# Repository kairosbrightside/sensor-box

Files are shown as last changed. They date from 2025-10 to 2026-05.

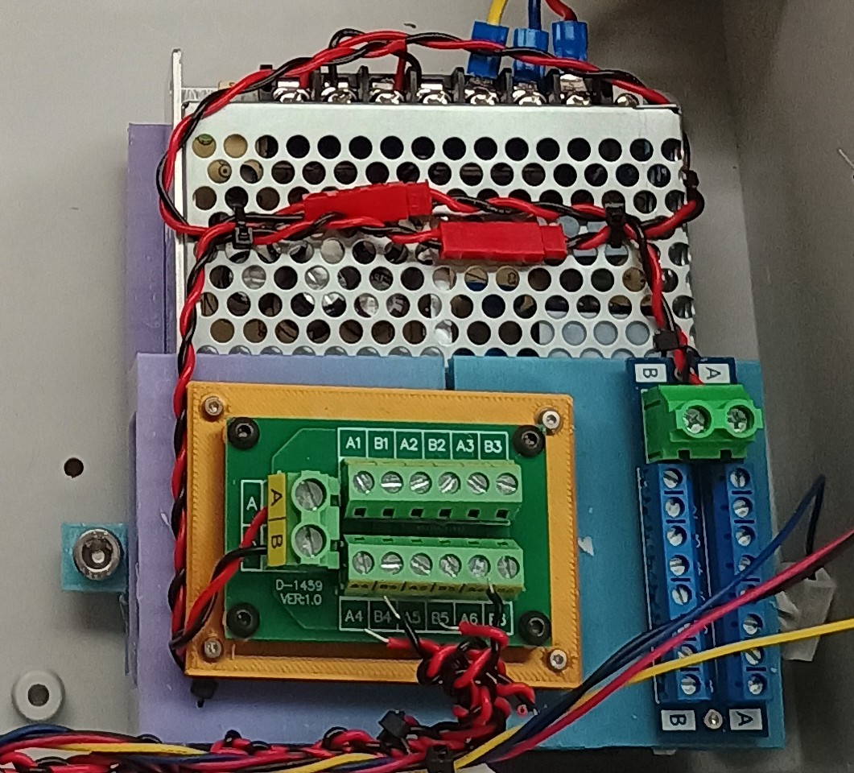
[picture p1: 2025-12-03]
images/powersupply.jpg

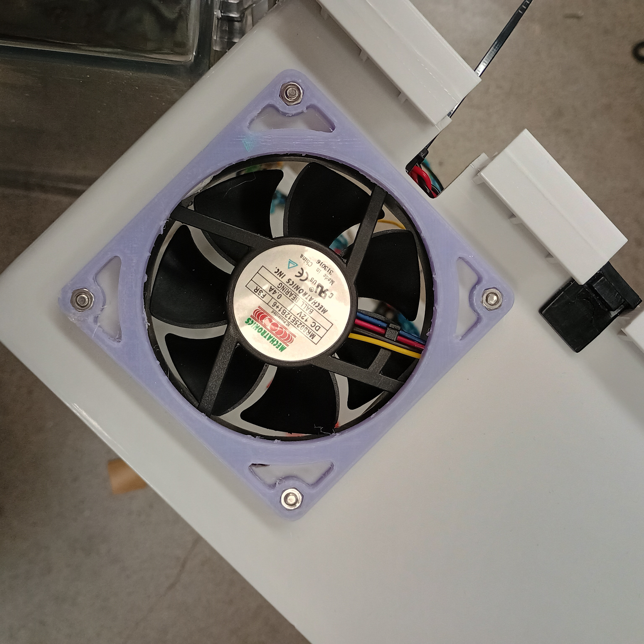
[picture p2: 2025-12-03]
images/fan.jpg

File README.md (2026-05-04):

# SensORV6
This Readme file contains information on the building and production of a Oregon SensOR box. The original information is found [here](https://github.com/ParticulateSensOR/SensORV6). Kairos here! I am building this as an expansion of a [project](https://github.com/kairosbrightside/sps30-pi) I did last summer (electrical documentation can be found there for the SPS30 sensor). I was supposed to do this like 2 months ago but I took too long on the autosampler `</3`. 

# Purpose
Sensor interface for real-time particulate monitoring using the SPS30 and Raspberry Pi, with CSV logging support.

# Equipment list 
| Component | Description / Model | Notes | Have? |
|---|---|---|---|
| PM2.5 Sensor | Plantower PMs5003ST | Measures particulate matter | ☑️ |
| PM2.5 Sensor | Sensirion SPS30 sensor | Measures particulate matter | ☑️ |
| Power Supply | RID-65A Meanwell (5V/12V) or RT-65D (5V/24V/12V) | Provides power etc | ☑️ |
| Computer | Raspberry Pi 5 | Main system controller | ☑️ |
| SD Card | SanDisk 64 GB SD Card | Storage for OS & data | ☑️ |
| Auto-Zero Valve | US Solid Motorized Ball Valve | Valve | ☑️ |
| 2x6 Terminal block | [Amazon Link](https://www.amazon.com/dp/B09D3BV22M?ref=ppx_yo2ov_dt_b_fed_asin_title) | Makes wiring easier | ☑️ |
| Heating Element | [Amazon Link](https://www.amazon.com/dp/B0CLS34QN2?ref=ppx_yo2ov_dt_b_fed_asin_title) | Heating | ☑️ |
| GPIO Terminal Block w/LED  | [Amazon Link](https://www.amazon.com/dp/B09QXR6RL7?ref=ppx_yo2ov_dt_b_fed_asin_title) | Easier GPIO wiring + indicators | ☑️ |
| Relay Board / RPi Hat | [Amazon Link](https://www.amazon.com/dp/B07CZL2SKN?ref=ppx_yo2ov_dt_b_fed_asin_title) | Turns stuff on and off | ☑️ |
| Diaphragm Pump | <Will Insert Later> | Supplies clean reference air | ☑️ |
| Rheostat | <Will Insert Later> | Adjusts current / heating power | ☑️ |
| Sensor Box | <Will Insert Later> | Enclosure for system | ☑️ |
| 80 mm computer fan | generic? | Fan | ☑️ |

Plus wire, connectors, filament, screws, tools, etc?

# Picture
SensOR box

Plantower sensor pinout


### wiring table 
| Physical Pin | BCM | Function  | Connection |
|---|-----|---|---|
| 6 | — | GND | Ground for ALL devices |
| 7 | 4 | GPIO4 | Button |
| 8 | 14  | TXD0 | SPS30 → RX  (UART0) |
| 10 | 15  | RXD0 | SPS30 ← TX (UART0) |
| 11 | 17  | GPIO17 | Fan tachometer |
| 27 | 0 | TXD1 | Plantower #1 → RX (UART1 TX → Pi RX)  |
| 28 | 1 | RXD1 | Plantower #1 ← TX (UART1 RX ← Pi TX)  |
| 32 | 12  | TXD4 | Plantower #2 → RX (UART4 TX → Pi RX)  |
| 33 | 13  | RXD4 | Plantower #2 ← TX (UART4 RX ← Pi TX)  |
| 37 | 26  | GPIO26 | Plantower power (Relay1) |
| 38 | 20  | GPIO20 | Heater (Relay2) |
| 40 | 21  | GPIO21 | Zero pump  (Relay3, NC) |
| 40 | 21  | GPIO21 | Valve  (Relay3, NO) |



> Note: we are skipping UART2 since we are using gpio 4 (physical pin 7) for something else

### changing UART settings
``` /boot/firmware/config.txt```
```bash
enable_uart=1
dtoverlay=uart1
dtoverlay=uart4
```
##### Checking changed UART settings:
Use 
```bash
ls /dev/ttyAMA*
```
to make sure all the desired ports (0,1,4) are available. When sensors are connected, check output with 
```bash
sudo cat /dev/ttyAMA0
sudo cat /dev/ttyAMA1
sudo cat /dev/ttyAMA4
```
### 5V devices:
Particle sensors (3x), level shifters

### Connect to Pi 3.3V output
The `SET` and `RESET` pins of the Plantower sensors.

### 12V devices:
Fan, Pumps, motorized ball valce, heater strip+ (rheostat)

## System functions:
The system takes in air through the top, when the valve is open and the relay is connected to the NO terminal. When the valve is closed, the zero air pump is calibrating the system by running zero air through it. The fan at the bottom blows out the air. The heater in the tube keeps temperature constant to ensure a constant volume enters the sample chamber.

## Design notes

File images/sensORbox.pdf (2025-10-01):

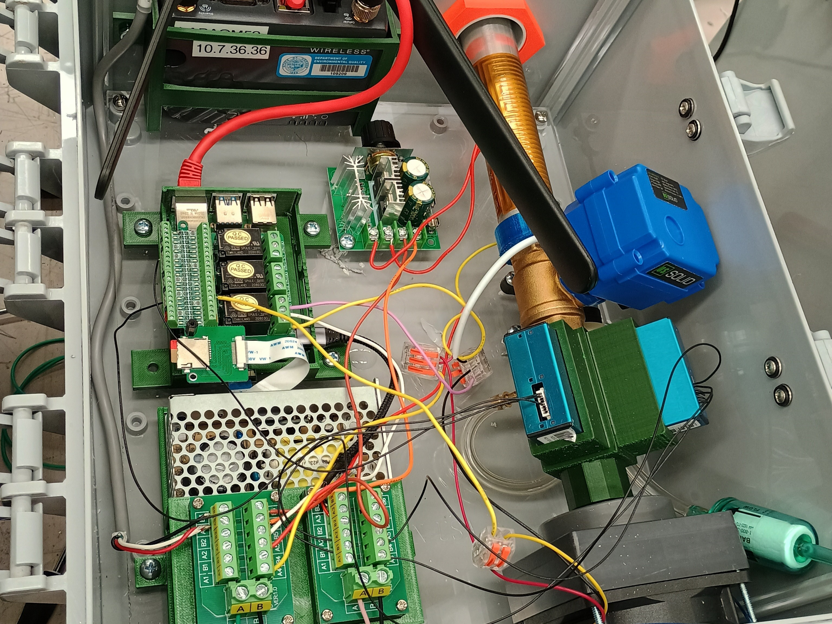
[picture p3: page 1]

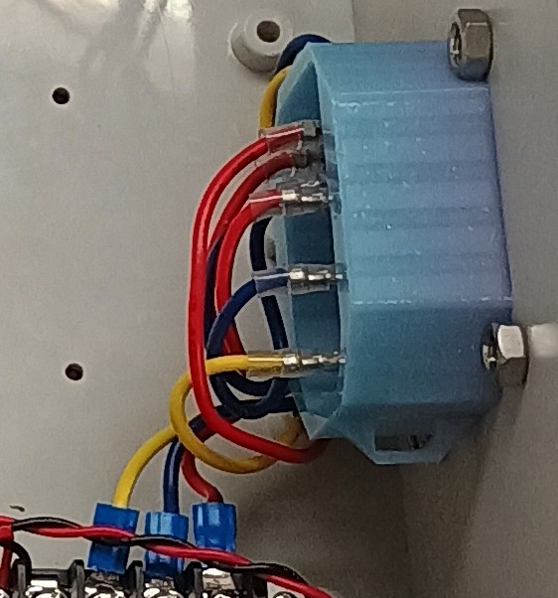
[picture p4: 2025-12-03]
images/systempowerback.jpg

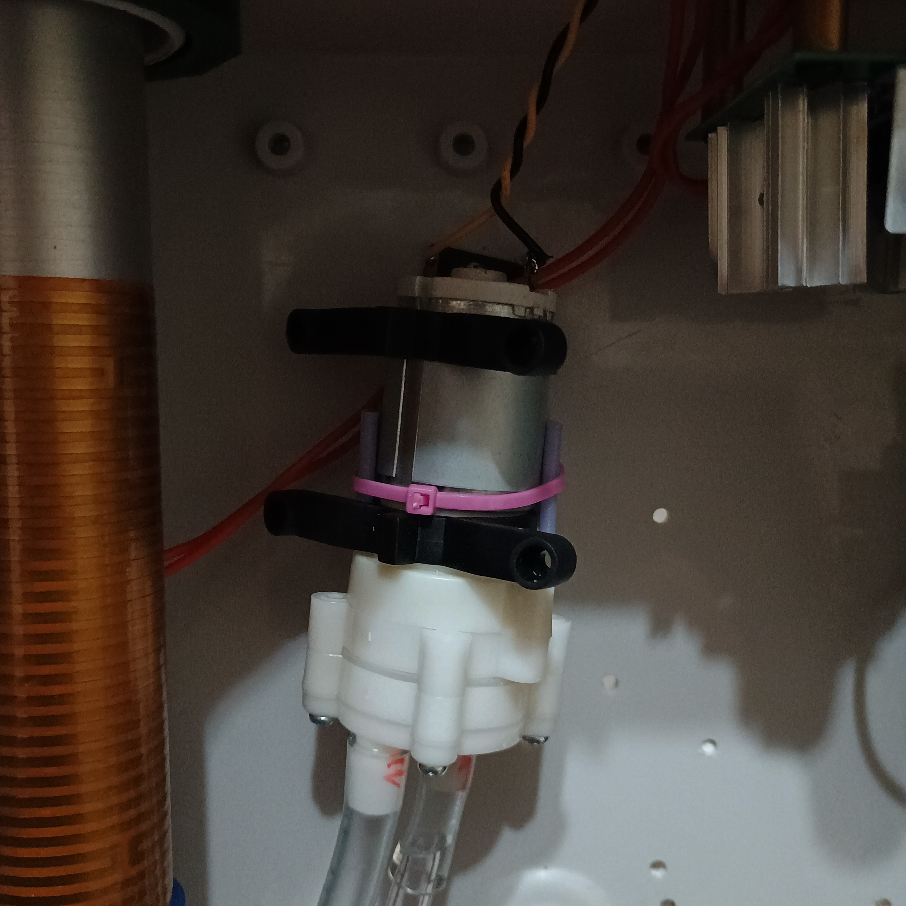
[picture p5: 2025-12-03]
images/pump.jpg

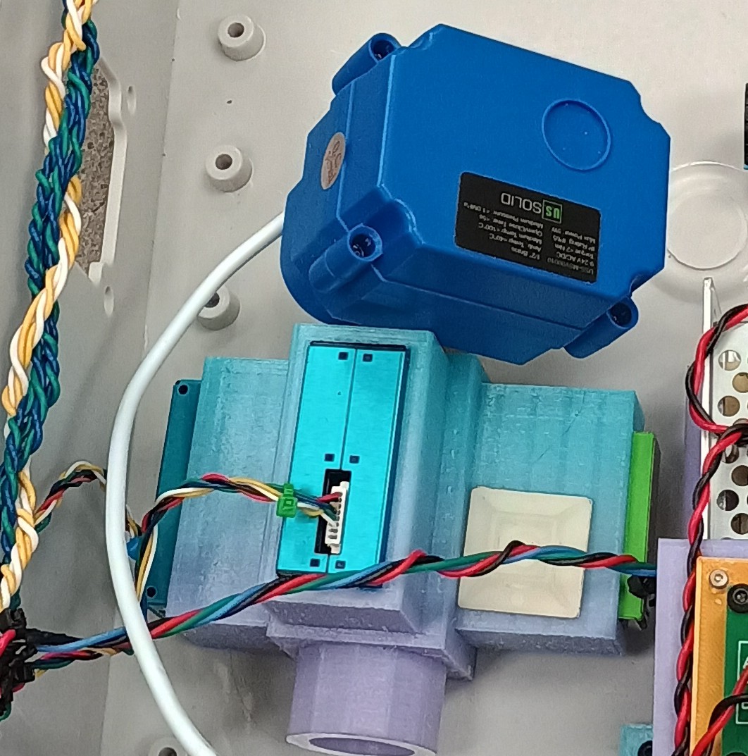
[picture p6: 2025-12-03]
images/samplechamber.jpg

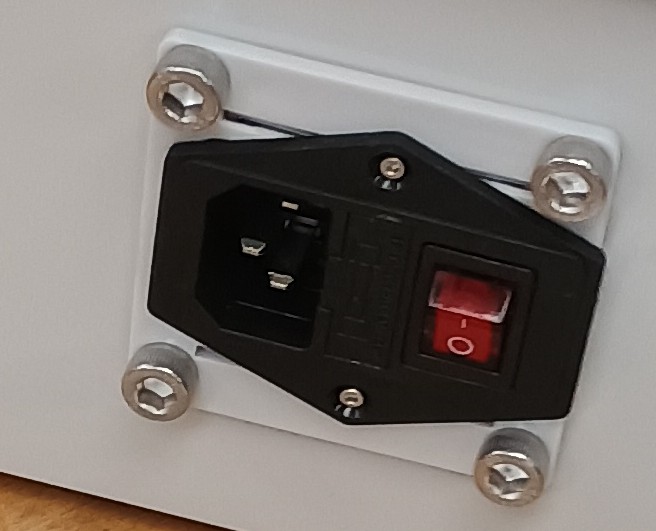
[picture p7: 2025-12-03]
images/sytstempower.jpg

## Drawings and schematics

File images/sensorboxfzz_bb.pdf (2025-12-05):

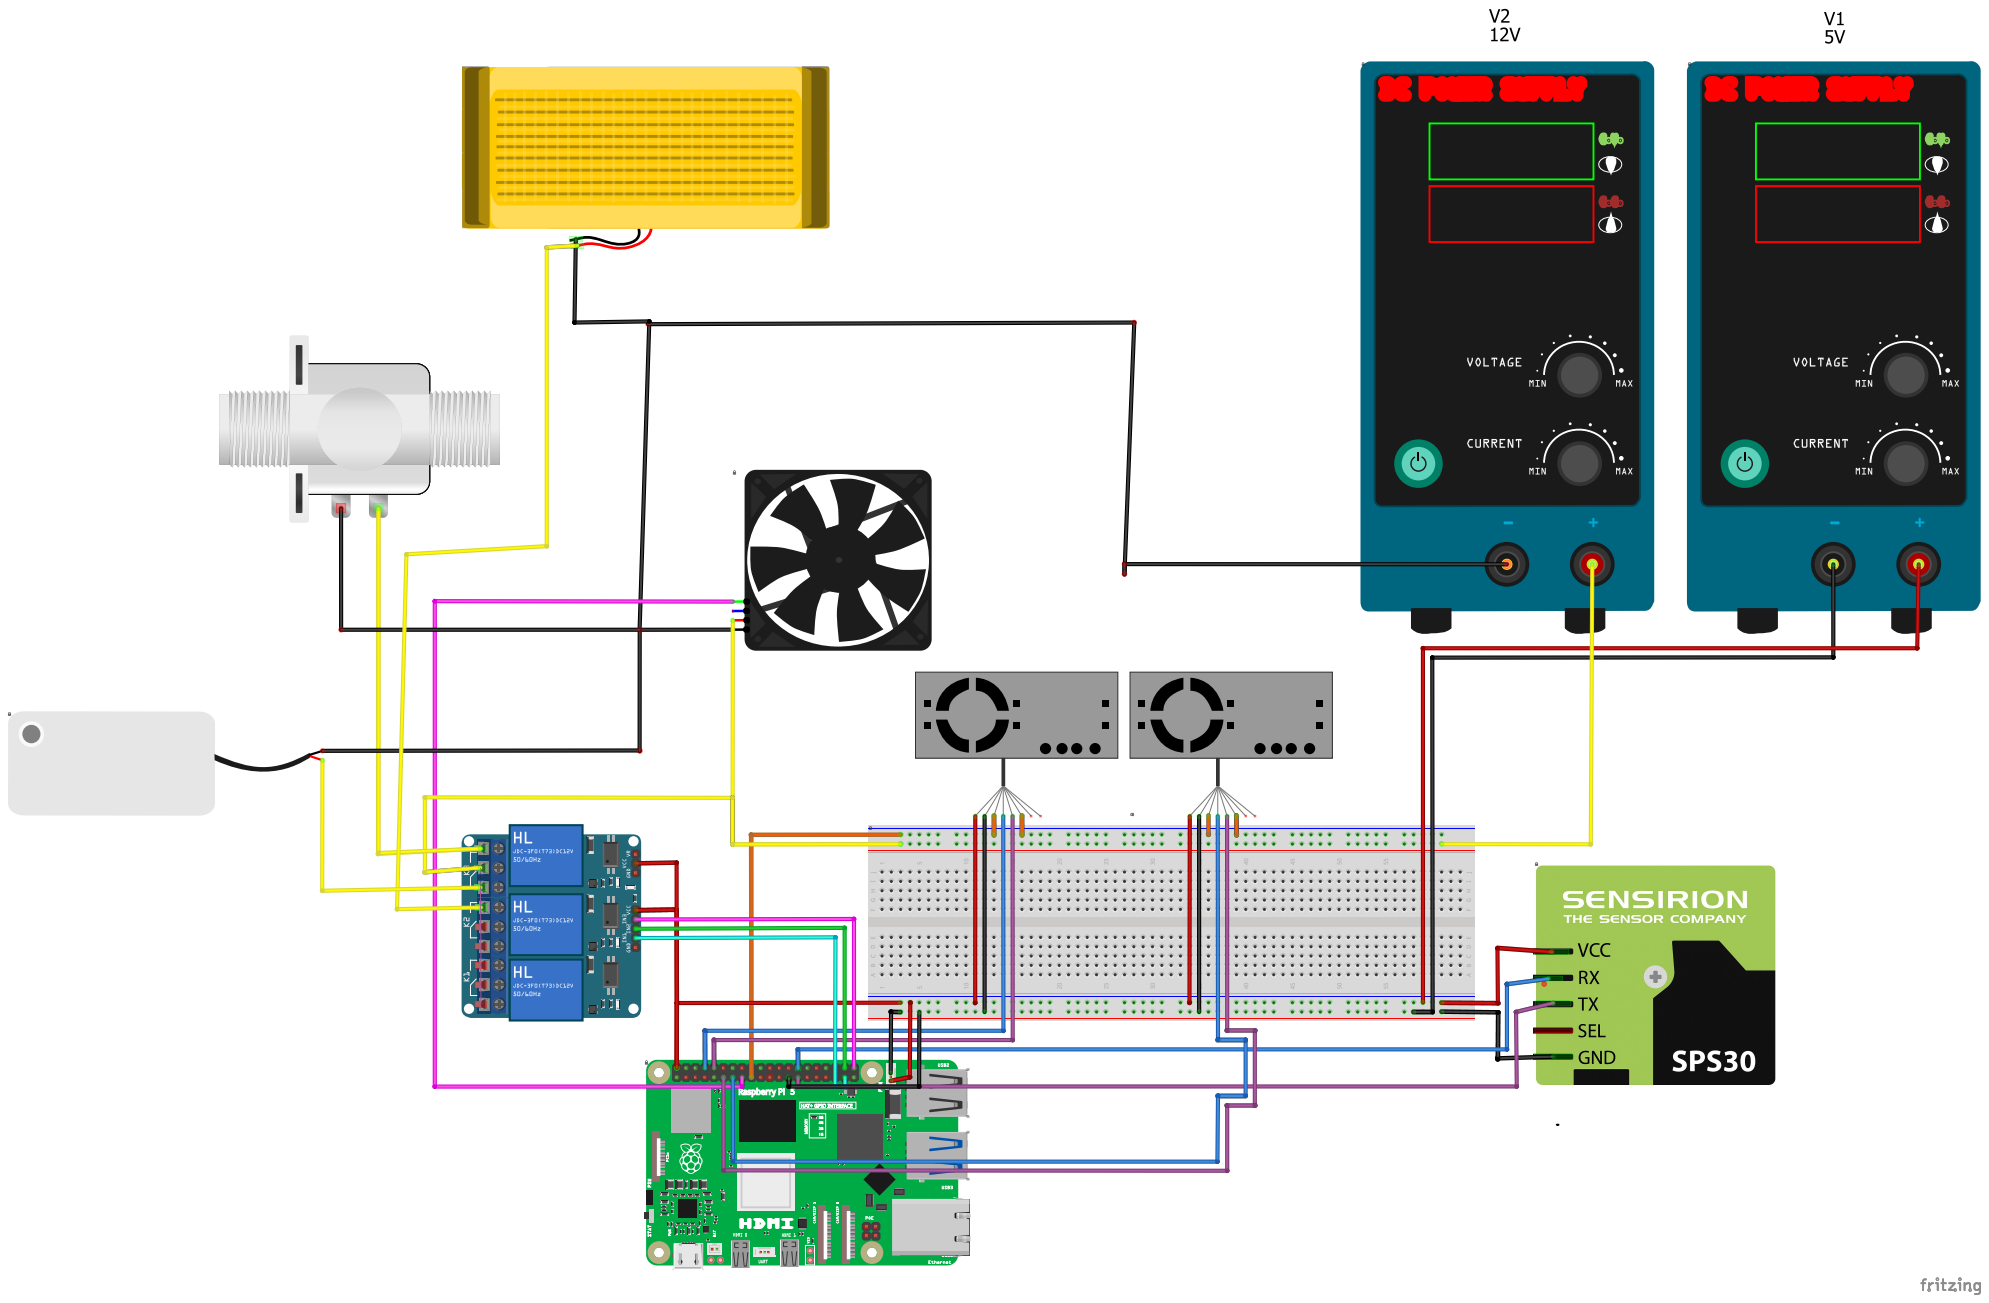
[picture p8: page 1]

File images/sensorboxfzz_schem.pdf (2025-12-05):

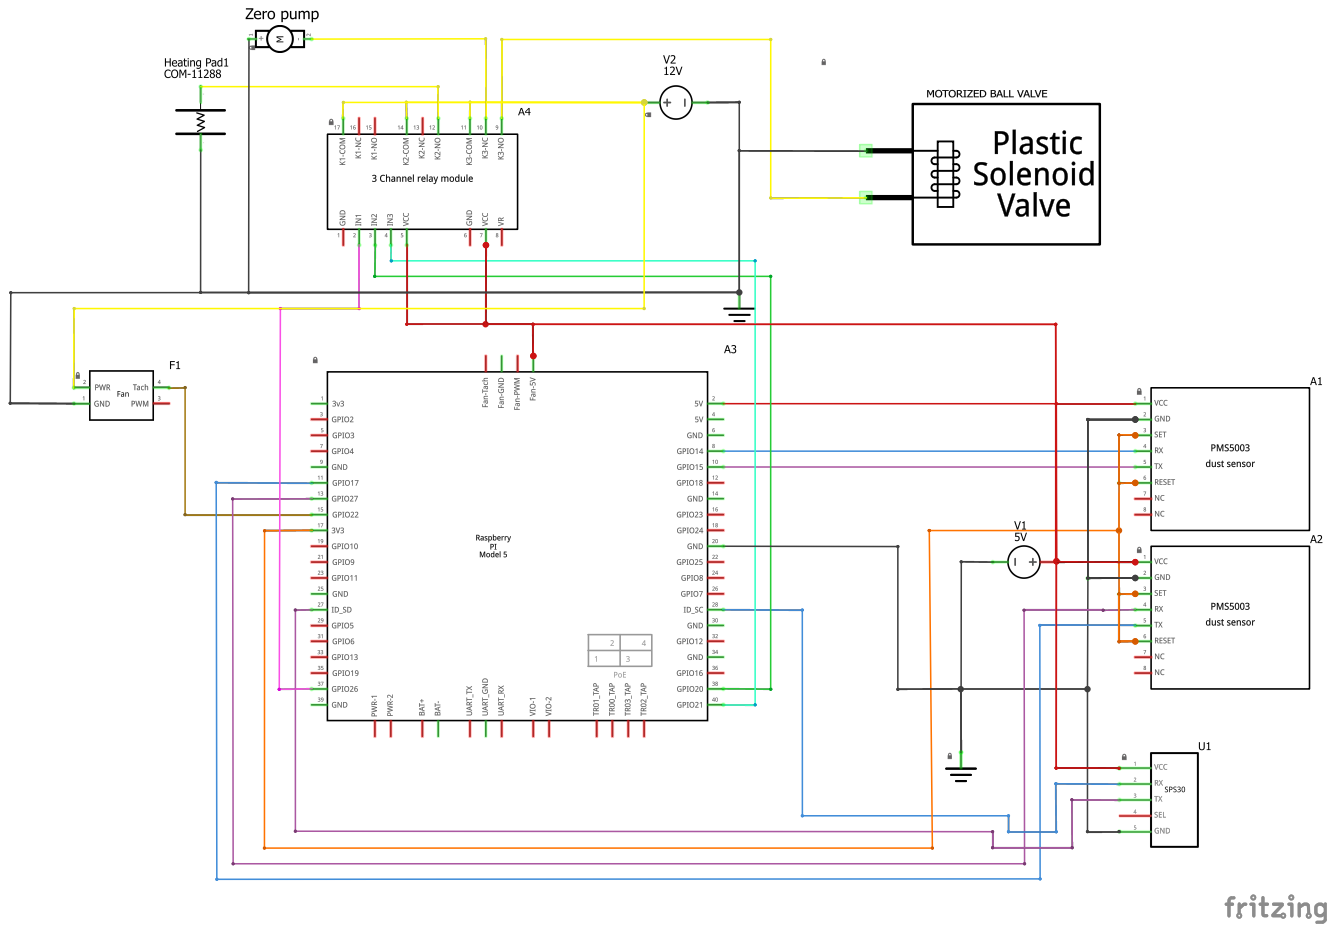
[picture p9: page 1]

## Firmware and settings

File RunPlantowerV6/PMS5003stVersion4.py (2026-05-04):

#This script reads data from PMS5003st sensors 
# The script is broken into 10 sections:
##(0) import libraries 
##(1) inputs for shell
##(2) make a log file
##(3) define functions
##(4) write header
##(5) On RPi storage - daily records & init minute data for shipping
##(6) check zero
##(7) establish RPi-plantower serial connection 
##(8-10) read plantower data, aggregate, and write to disk

# updated 9DEC2020 by AWF
#########################################  
#(0) libraries
##########################################
import os, sys
import shutil

import datetime, time
import serial
import RPi.GPIO as GPIO
import numpy as np
import pandas as pd

import logging

import struct

#########################################  
#(1) input from shell & adjust here
#########################################
site = sys.argv[1]
site = str(site)

##
sn = sys.argv[2]
sn = str(sn)

##
Port2Focus = sys.argv[3]
Port2Focus = str(Port2Focus)

# uncomment for testing
#site="BOX"
#sn="2"
#Port2Focus="ttyAMA1"

#adjust here
code_version = 4
sensorType = "PMS5003st"
DataOutDirectory = "/media/particulatepi/data/PMoutputData/" #output directory

SampleRate = 2 #sec - pause n seconds between measurements

######################################### 
#(2) create log
######################################### 
fleLog = (DataOutDirectory + site + "_" + sensorType + "_sn" + sn + "_" + "Log.txt")

logger = logging.getLogger(__name__)
logger.setLevel(logging.DEBUG)

formatter = logging.Formatter('%(asctime)s:%(filename)s:%(funcName)s:%(levelname)s:%(levelno)s:%(message)s')

file_handler = logging.FileHandler(fleLog)
file_handler.setFormatter(formatter)

logger.addHandler(file_handler)

######################################### 
#(3) functions 
#########################################
# connect to the sensor
def plantower_serial_connection(_serPort):
    '''Establishes serial connection between RPi and plantower:
    inputs: _serPort = RPi port attached to plantower
    
    returns: ser = serial object for the plantower connection
    ErrorFlag = error message associated with a failed serial connection w/"none" == no errors/connection is OK''' 
    
    ErrorFlag = 'init'
    IsPortOpen = False
    nTrys = 0
    
    while ((IsPortOpen == False) & (nTrys <= 3)):
        
        #make a connection
        try:
            ser = serial.Serial() #serial object
            ser.port = '/dev/' + _serPort  
            ser.baudrate = 9600
            ser.stopbits = serial.STOPBITS_ONE
            ser.parity = serial.PARITY_NONE
            ser.bytesize = serial.EIGHTBITS
            ser.timeout = 5
            
            ser.open()
            IsPortOpen = ser.is_open
            ErrorFlag = 'none'
            
        except:
            
            nTrys += 1
            logger.info('Could not make a serial object.')
            time.sleep(1)#pause
    
    return(ser, ErrorFlag)


# read in the serial string from the plantower and do basic QA/QC
def read_pm_line(_port):
    '''Reads serial data from plantower
    inputs: _port = serial object from plantower_serial_connection
    
    return:
    rv is the data (serial string) from the plantower
    error_read_pm_line = error message associated with a failed serial read w/ "none" == all OK'''
    
    #initialize
    nSearchForStartReads = 0
    rv = b''
    error_read_pm_line = 'error_read_pm_line'
    
    #do the read
    while ((error_read_pm_line != 'none') & (nSearchForStartReads < 100)):
        try:
            nSearchForStartReads += 1
            
            #PMS5003st gives a 40 character string
            ch1 = _port.read()
            if ch1 == b'\x42':
                ch2 = _port.read()
                if ch2 == b'\x4d':
                    rv += ch1 + ch2
                    rv += _port.read(38)
                    
                    error_read_pm_line = 'none'

        except:
            rv = b''
            
    return(rv, error_read_pm_line)
            
# error check for incoming serial data          
def read_pm_error_check(rv, error_read_pm_line):
    '''Error checking on read_pm_line'''
    
    err_check = error_read_pm_line
    
    ##check if a base error was thrown
    if (error_read_pm_line != 'none'):
        logger.info('error_read_pm_line')
        err_check = 'err_flag'
    ##did not get a read
    if (rv == b''):
        logger.info('EmptyReadLine')
        err_check = 'err_flag'
    ##length 
    if (len(rv) != 40):
        logger.info('ReadLineLengthError')
        err_check = 'err_flag'
    ##check sum 
    if (len(rv) == 40):
        DataSum = sum(rv[0:37])
        cksum = (rv[38] * 256 + rv[39])
        if (DataSum != cksum):
            logger.info('CheckSumFailError')
            err_check = 'err_flag'
    
    return(rv, err_check)
    
# file management - check read-write      
def SetupDataFile(fleOut, writetype):
    '''check file permissions'''
    
    if os.path.exists(fleOut) == True:
        logger.info('Restarting Run: Appending data to' + fleOut) 
    else:
        try:
            file2write = open(fleOut, writetype)
            file2write.close()
        except:
            logger.info('Setup file Error')
            
        OKfilePermission = (os.access(fleOut, os.R_OK)) & (os.access(fleOut, os.W_OK)) #read-write privaleges?
        if (OKfilePermission == False):
            logger.info('File Permission Error: ' + fleOut + ' Exiting!') 
            sys.exit(1) #exit


def init_dataout(fleoutAVG, PMheader):
    '''init data to file'''
    
    InitData = pd.DataFrame(999, index=range(0,1), columns = PMheader) # initialize

    try:
        with open(fleoutAVG, 'w') as myfile:
            InitData.to_csv(myfile, header=False, index=False)
    except:
        logger.info("data.csv did not initalize.")
  
  
#######d##################################
#(4) write the header to disk
#########################################
fleHeader = (DataOutDirectory + site + "_" + sensorType + "_sn" + sn + "_" + "DataHeader.txt")
    
PMheader = ["year", "month", "day", "hour", "minute", "second",
            "apm1_0", "apm2_5", "apm10",
            "pm1_0", "pm2_5", "pm10",
            "gt03um", "gt05um", "gt1_0um", "gt2_5um", "gt5_0um", "gt10um",
            "form",
            "T_K",
            "rh", "zero",
            "code_version", "sn"]

HeaderLine = ",".join(PMheader) + "\n"

with open(fleHeader, "a") as myfile:
    myfile.write(HeaderLine)
               
######################################################################
## (5) On RPi storage - daily records & init minute data for shipping
######################################################################
DateStr4Out = str(datetime.datetime.now().day) + '_' + str(datetime.datetime.now().month) + '_' + str(datetime.datetime.now().year)
        
fleoutFSTDaily = (DataOutDirectory + site + "_" + sensorType + "_sn" + sn + "_" + "1sec" + DateStr4Out + ".txt")
SetupDataFile(fleoutFSTDaily, "a")       
        
fleoutAVGDaily = (DataOutDirectory + site + "_" + sensorType + "_sn" + sn + "_" + "1Min" + DateStr4Out + ".txt")
SetupDataFile(fleoutAVGDaily, "a")

# setup the file for data that will be loaded to the modbus server - this will get updated every minute
fleoutAVG = (DataOutDirectory + site + '_' + sensorType + "_sn" + sn + "_" + "1Min.txt")
SetupDataFile(fleoutAVG, "a")
init_dataout(fleoutAVG, PMheader)

########################################
## (6) check zero 
#########################################
 
try:
    pinhigh = GPIO.input(21)
except:
    logger.info("PMS5003st code set the zero pin to low.")
    GPIO.setmode(GPIO.BCM) # updated BCM to BOARD 12SEP2023
    GPIO.setup(21, GPIO.OUT)
    GPIO.output(21, GPIO.LOW)
    pinhigh = 0
    
#########################################
# (7) Connect to sensor
#########################################
ser, ConnectionError = plantower_serial_connection(Port2Focus)

if (ConnectionError == 'none'):
    logger.info("Connected to " + sensorType) 
else:
    ### Give up and report the failure
    logger.info("Exiting " + sensorType + " connection: " + str(ConnectionError)) 
    sys.exit(1) #exit 

########################################
# (8) Read serial data from plantower
########################################
#Initialize
iter = 0
MeasureTime = datetime.datetime.utcnow() - datetime.timedelta(hours=8)
Day_previous = MeasureTime.day
minute_past  = MeasureTime.minute

#Initiate a dataframe for the incoming data
DataIn = pd.DataFrame(999, index=range(0,1),columns=PMheader)

IndRow = 0
 
while True:
    try:
        
        #sets sampling rate
        time.sleep(SampleRate) 
            
        #time - should not observe daylight savings
        MeasureTime = datetime.datetime.utcnow() - datetime.timedelta(hours=8)
        
        #Clear input buffer to avoid lagging, was done after each minute before
        ser.flushInput()
        
        rcv, error_read_pm_line = read_pm_line(ser) #read in serial data
        
        # for troubleshooting
        # print(rcv)
        
        rcv, read_error = read_pm_error_check(rcv, error_read_pm_line)

        # for troubleshooting
        # print(rcv)
        # print(read_error)
        
        if (read_error == 'none'):
            #Parse rcv serial string to DataIn: see PMS5003st manual for var. assignments
            DataIn.loc[IndRow,"year"]  = int(MeasureTime.year)        #time block
            DataIn.loc[IndRow,"month"]  = int(MeasureTime.month)
            DataIn.loc[IndRow,"day"]  = int(MeasureTime.day)
            DataIn.loc[IndRow,"hour"]  = int(MeasureTime.hour)
            DataIn.loc[IndRow,"minute"]  = int(MeasureTime.minute)
            DataIn.loc[IndRow,"second"]  = int(MeasureTime.second)
                
            DataIn.loc[IndRow,"apm1_0"]  = int(rcv[4] * 256 + rcv[5])    #apm block
            DataIn.loc[IndRow,"apm2_5"]  = int(rcv[6] * 256 + rcv[7])                
            DataIn.loc[IndRow,"apm10"]  = int(rcv[8] * 256 + rcv[9])                
                
            DataIn.loc[IndRow,"pm1_0"]  = int(rcv[10] * 256 + rcv[11])  #pm block
            DataIn.loc[IndRow,"pm2_5"] = int(rcv[12] * 256 + rcv[13])             
            DataIn.loc[IndRow,"pm10"] = int(rcv[14] * 256 + rcv[15])              
                   
            DataIn.loc[IndRow,"gt03um"] = int(rcv[16] * 256 + rcv[17]) #gt block
            DataIn.loc[IndRow,"gt05um"] = int(rcv[18] * 256 + rcv[19])
            DataIn.loc[IndRow,"gt1_0um"] = int(rcv[20] * 256 + rcv[21])
            DataIn.loc[IndRow,"gt2_5um"] = int(rcv[22] * 256 + rcv[23])
            DataIn.loc[IndRow,"gt5_0um"] = int(rcv[24] * 256 + rcv[25])
            DataIn.loc[IndRow,"gt10um",] = int(rcv[26] * 256 + rcv[27])
                   
            DataIn.loc[IndRow,"form"] = int(((rcv[28] * 256 + rcv[29])/1000))  #formaldehyde
                
            # there is a multiplier = 10 from the plantower
            DataIn.loc[IndRow,"T_K"] = int(round((((struct.unpack('>20h',rcv)[15])/10) + 273.15) * 10, 0))  #temp in Kelvin
            
            DataIn.loc[IndRow,"rh"] = int(rcv[32] * 256 + rcv[33]) #rh * 10
            
            DataIn.loc[IndRow,"zero"] = int(GPIO.input(21)) #zero
            
            DataIn.loc[IndRow,"code_version"] = int(code_version) # version of code
            DataIn.loc[IndRow,"sn"] = int(sn) # sn
            
            #add 1 to row index for next loop
            IndRow += 1 
            
            # reset iter
            iter = 0
            
        elif ((read_error != 'none') & (iter > 50) & (iter <= 99)):
            ser, ConnectionError = plantower_serial_connection(Port2Focus)
            logger.info("Error: Restarting Connection")
            
            iter += 1
            
        elif ((read_error != 'none') & (iter > 99)):
            logger.info("## N try > 99, writing 999 to data")
            init_dataout(fleoutAVG, PMheader) # write out 999 to minute data on exit

        else:
            iter+=1

            
        ############################################################
        #(9) write data at 1 min. interval
        ############################################################
        #save data to disk
        minute_current = MeasureTime.minute
        
        if (minute_current != minute_past):
            
            minute2send = pd.DataFrame(999, index=range(0,1), columns=PMheader)
  
            try:
                #do the ENVIDAS aggregation
                
                minute2send.loc[0,"apm1_0"] = DataIn["apm1_0"].mean().round(0) #avg apm mass
                minute2send.loc[0,"apm2_5"] = DataIn["apm2_5"].mean().round(0)
                minute2send.loc[0,"apm10"] = DataIn["apm10"].mean().round(0)
                
                minute2send.loc[0,"pm1_0"] = DataIn["pm1_0"].mean().round(0) #avg pm mass
                minute2send.loc[0,"pm2_5"] = DataIn["pm2_5"].mean().round(0)
                minute2send.loc[0,"pm10"] = DataIn["pm10"].mean().round(0)
                
                minute2send.loc[0,"gt03um"] = DataIn["gt03um"].mean().round(0)  #avg particle counts
                minute2send.loc[0,"gt05um"] = DataIn["gt05um"].mean().round(0)
                minute2send.loc[0,"gt1_0um"] = DataIn["gt1_0um"].mean().round(0)
                minute2send.loc[0,"gt2_5um"] = DataIn["gt2_5um"].mean().round(0)
                minute2send.loc[0,"gt5_0um"] = DataIn["gt5_0um"].mean().round(0)
                minute2send.loc[0,"gt10um"] = DataIn["gt10um"].mean().round(0)
                
                minute2send.loc[0,"form"] = DataIn["form"].mean().round(0) #avg formaldehyde
                minute2send.loc[0,"T_K"] = DataIn["T_K"].mean().round(0) #avg temp
                minute2send.loc[0,"rh"] = DataIn["rh"].mean().round(0) #avg rh
                
                minute2send.loc[0,"zero"] = DataIn["zero"].mean().round(0) #doing zero
                
                minute2send.loc[0,"code_version"] = DataIn["code_version"].median().round(0) #code version
                minute2send.loc[0,"sn"] = DataIn["sn"].median().round(0) #sn
                
                minute2send.loc[0,"year"] = DataIn["year"].median().round(0) # time
                minute2send.loc[0,"month"] = DataIn["month"].median().round(0)
                minute2send.loc[0,"day"] = DataIn["day"].median().round(0)
                minute2send.loc[0,"hour"] = DataIn["hour"].median().round(0)
                minute2send.loc[0,"minute"] = DataIn["minute"].median().round(0)
                minute2send.loc[0,"second"] = DataIn["second"].median().round(0)
                
            except:
                logger.info("Minute could not be averaged. May be empty.")
            
            #Reset the minute for record keeping
            minute_past = minute_current
              
            try:
                with open(fleoutAVG, 'w') as myfile1:
                    minute2send.to_csv(myfile1, header=False, index=False, float_format='%.0f')
                    
                with open(fleoutAVGDaily, "a") as myfile2:
                    minute2send.to_csv(myfile2, header=False, index=False, float_format='%.0f')
                    
            except:
                logger.info("Error: Did not write data to server")
            
            ####### RPi Backup logs #########################   
            #save if there is free space
            total, used, free = shutil.disk_usage(DataOutDirectory)
            
            fracFree = free/total
            
            if (fracFree >= 0.3):
                #fast data
                try:
                    with open(fleoutFSTDaily, "a") as myfile:
                        DataIn.to_csv(myfile, header=False, index=False)
                except:
                    logger.info("Fast file write error")
                    
            else:
                logger.info("Low disk space. Stopped logging data to local site")
                
            #Reset DataIn for incoming data
            IndRow = 0
            DataIn = pd.DataFrame(np.nan, index=range(0,1),columns=PMheader)
            
        ############################################################
        #(10) new file every day
        ############################################################
        #make a new file for data output
        Day_current = MeasureTime.day
        
        if (Day_current != Day_previous):
            
            DateStr4Out = str(Day_current) + '_' + str(MeasureTime.month) + '_' + str(MeasureTime.year)

            fleoutFSTDaily = (DataOutDirectory + site + "_" + sensorType + "_sn" + sn + "_" + "1sec" + DateStr4Out + ".txt")
            SetupDataFile(fleoutFSTDaily, "a")       
            
            fleoutAVGDaily = (DataOutDirectory + site + "_" + sensorType + "_sn" + sn + "_" + "1Min" + DateStr4Out + ".txt")
            SetupDataFile(fleoutAVGDaily, "a",)
            
            Day_previous = Day_current
            
    except:
        
        logger.info("!!Crashed!!")
        init_dataout(fleoutAVG, PMheader) # write out 999 to minute data on exit
        ser.close() # close the serial connection
        sys.exit(1) # exit the program

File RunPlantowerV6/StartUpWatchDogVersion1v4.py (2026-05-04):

#Watchdog to check if the sensor package started correctly
#alerts OP if box is working or not

##WORKING == 20 quick continuous pump buzzes
##NOT WORKING == 5 syncopated pump buzzes

#Check @ startup includes:
#(1) Check if the internet is working
#(2) Check if all key python scripts started
#(3) Check if the data that is being written to file is current with RPi time

#This script was modified to check if the button script is running

#Change as needed:
RunPMShell = '/home/particulatepi/RunPlantower/RunPMShell.sh'
DataDir = '/media/particulatepi/data/PMoutputData/' #Where is the data stored?
ip2ping = '192.168.13.101'      #Modem gateway connected to RPi?
#ip2ping = '192.168.1.1'      #Modem gateway connected to RPi?

#libraries
import sys
import subprocess, os
import datetime, time
import RPi.GPIO as GPIO 

import CheckOperationVersion1v3 as CheckOP

#main
def doWatchDog(print2screen):
    if (print2screen == 1):
        print('Print diagnostics to screen:')
                
    #(0) Init
    #setup GPIO pins
    GPIO.setwarnings(False)
    GPIO.setmode(GPIO.BCM)
    GPIO.setup(21, GPIO.OUT)

    #tell the OP that the box started the watchdog
    CheckOP.AlertOPpause(1)
    
    #init parameters for checks; 0 = off; 1 = on
    InternetUp = 0
    ScriptsUp = 0
    FilesUp = 0

    ### Main script ###
    #(1) Check if the box is connected to the internet
    if (print2screen == 1):
        print('Is the internet up:')
        
    FailedConnection = 0
    nTry = 60 # 0.5 min. trys

    while(InternetUp == 0):
        
        time.sleep(1) 
        
        PacketLoss = CheckOP.CheckInternet(ip2ping)
            
        if(PacketLoss == 0):
            InternetUp = 1
            if (print2screen == 1):
                print('Internet OK')
        else:
            InternetUp = 0
            FailedConnection += 1
        
        #try restarting networking if the internet is down
        if(FailedConnection == round(nTry/2)):
            try:
                if (print2screen == 1):
                    print('Could not ping modem:')
                    print('restart network connection')
                subprocess.run(['systemctl', 'restart', 'networking'])
            except:
                pass
        
        #alert OP if we did not establish a connection
        if(FailedConnection >= nTry):
            if (print2screen == 1):
                print('no connection')
            break
            
    #(2)Check if all the python programs started up?
    if (print2screen == 1):
        print('Check if scripts are running:')
                    
    FailedScript = 0
    nTry = 10 # 120 trys - 2 minutes

    while(ScriptsUp == 0):
        
        PythonUpTEMP = subprocess.Popen(['ps', '-ef'], stdout=subprocess.PIPE) #will this close itself?
        PythonUp = subprocess.check_output(['grep', 'python3.9'], stdin=PythonUpTEMP.stdout)
        PythonUp = PythonUp.decode("utf-8")

        serverStart = PythonUp.find("UpdateServer")
        plantowerStart = PythonUp.find("PMS5003stVersion")
        serialConnectionStart = PythonUp.find("ttyAMA0")
        usbConnectionStart = PythonUp.find("ttyAMA1")
        zeroStart = PythonUp.find("DoZero")
        # buttonStart = PythonUp.find("Button")
        
        #if any of the scripts are not running, kill all python processes and then restart them
        if((serverStart == -1)|(plantowerStart == -1)|(serialConnectionStart == -1)|(usbConnectionStart == -1)|(zeroStart == -1)):
                
            # subprocess.run(['sudo pkill -9', 'python'])
            
            CheckOP.RestartRunPMShell(RunPMShell)   
            
            FailedScript+=1
            
            if (print2screen == 1):
                print('script error: restarting scripts')
            
            time.sleep(15)
            
        else:
            ScriptsUp = 1
            if (print2screen == 1):
                print('scripts OK')
            
        #shutdown if we could not establish a connection
        if FailedScript >= nTry:
            if (print2screen == 1):
                print('scripts not running')
            break
        
    #(3) Check if current data is written to file
    if (print2screen == 1):
        print('SensOR clock says the time is:')
        print(datetime.datetime.now())
        print('Check if the datafile contains the current time:')
        
    FleInDir = os.listdir(DataDir)
    WhatIsLateInMin = 2 # it takes around 3 minutes to assure an update

    #How many 1 Min files are there?
    HowManyFilesShouldBeUpdated = 0

    #Get the number of files that should be updated
    for items in FleInDir:
        WhatFle = items.find('1Min.txt')
        if(WhatFle != -1):
            HowManyFilesShouldBeUpdated+=1

    #How many of these files are updated?
    FailedUpdate = 0
    nTrys = 100

    while (FilesUp == 0):
        
        nUpdatedFiles = CheckOP.IsLateMeasurement(DataDir, FleInDir, WhatIsLateInMin)
        
        if(nUpdatedFiles == HowManyFilesShouldBeUpdated):
            if (print2screen == 1):
                print('Data OK')
            FilesUp = 1
        else:
            FilesUp = 0
            
        #restart shell if proc are not updating
        if ((FilesUp == 0) & (FailedUpdate == (nTrys/2))):
            
            CheckOP.RestartRunPMShell(RunPMShell)
            
            if (print2screen == 1):
                print('Data not current: try restarting scripts')
                
            time.sleep((WhatIsLateInMin*60)/nTrys) #equally spaced effort
            
        if ((FilesUp == 0) & (FailedUpdate > nTrys)):
            if (print2screen == 1):
                print('Data not current: giving up - check plantower connections')
            break
        
        FailedUpdate+=1 
        time.sleep((WhatIsLateInMin*60)/nTrys)
        
        
    #(4)Alert the tech that the box started up OK or not
    ## if not --> shutdown
    if (InternetUp == 1) & (ScriptsUp == 1) & (FilesUp == 1):
        CheckOP.AlertOPcontinue(20) #long buzz to alert OP that everything is OK @ startup
        if (print2screen == 1):
            print('Sensor All OK')
    else:
        CheckOP.AlertOPpause(5)
        if (print2screen == 1):
            print('Sensor not working: action needed.')
            
    #(5)About SensOR
    if (print2screen == 1):
        print('About this sensor:')
        print(subprocess.run(['lsb_release', '-irdc']))
        print(subprocess.run(['cat', '/proc/device-tree/model']))


#now do the watchdog
if(__name__ == '__main__'):
    
    #from shell
    print2screen = sys.argv[1]
    print2screen = int(print2screen)

    doWatchDog(print2screen)
    #GPIO.cleanup()
    

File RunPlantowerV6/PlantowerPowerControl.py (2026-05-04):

import RPi.GPIO as GPIO
import time
import os

# Configuration
PIN = 26  # GPIO pin to control
FILE_PATH = '/media/particulatepi/data/PMoutputData/PlantowerRelay.txt'
DEFAULT_STATE = '[0]'  # Default value if file doesn't exist
CHECK_INTERVAL = 5  # Seconds between checks

# Setup GPIO
GPIO.setmode(GPIO.BCM)
GPIO.setup(PIN, GPIO.OUT)

# Initialize current GPIO state
last_state = None

try:
    while True:
        # Create file if it doesn't exist
        if not os.path.exists(FILE_PATH):
            with open(FILE_PATH, 'w') as f:
                f.write(DEFAULT_STATE)

        # Read file content
        with open(FILE_PATH, 'r') as f:
            state = f.read().strip()

        # Validate and apply state if it's different
        if state in ['[0]', '[1]']:
            if state != last_state:
                GPIO.output(PIN, GPIO.HIGH if state == '[1]' else GPIO.LOW)
                last_state = state

        time.sleep(CHECK_INTERVAL)

except KeyboardInterrupt:
    pass

except Exception:
    pass

finally:
    GPIO.cleanup()

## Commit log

2025-06-26 Create Code Descriptions
    Creating a Code Description for Sensor Box
2025-06-26 Add files via upload
    Plantower Power Control
2025-10-01 Added picture of sensOR box
    From when Alex and I visited the DEQ
2025-11-21 added script for all 3 sensors communicating through uart
2025-12-01 What I have for a schematic so far!
    [sensorboxfzz.fzz]
2025-12-05 added Fritzing schematics
2026-02-05 try to initialize sps30 on UART4
2026-03-30 Update imports for ButtonVersion2.py
2026-04-16 reinventing the wheel, possibly
2026-05-04 modified: ../README.md modified: button_control.py deleted: do_zero.py modified: logger.py modified: periodic_restart.py deleted: plantower_power_control.py modified: rpm_counter.py modified: run_pm_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
2026-05-29 working stuff
    [PSU_2026_04_13.csv, PSU_2026_04_14.csv, PSU_2026_04_20.csv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]
2026-05-29 organizational changes
    [PSU_2026_04_13.csv, PSU_2026_04_14.csv, PSU_2026_04_20.csv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]
